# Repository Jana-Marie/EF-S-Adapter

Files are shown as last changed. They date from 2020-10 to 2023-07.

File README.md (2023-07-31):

# EF-S-Adapter

Hard- and Firmware to control EF/EF-S lenses. The protocol used has grown since the first generation of EF(-S) lenses hence is a bit extensive with different layers of compatibility. On the physical layer a SPI like interface is used with I2S alike clock-stretching. 

**Please use at your own risk, the hard- and firmware are experimental and can damage your lens!**

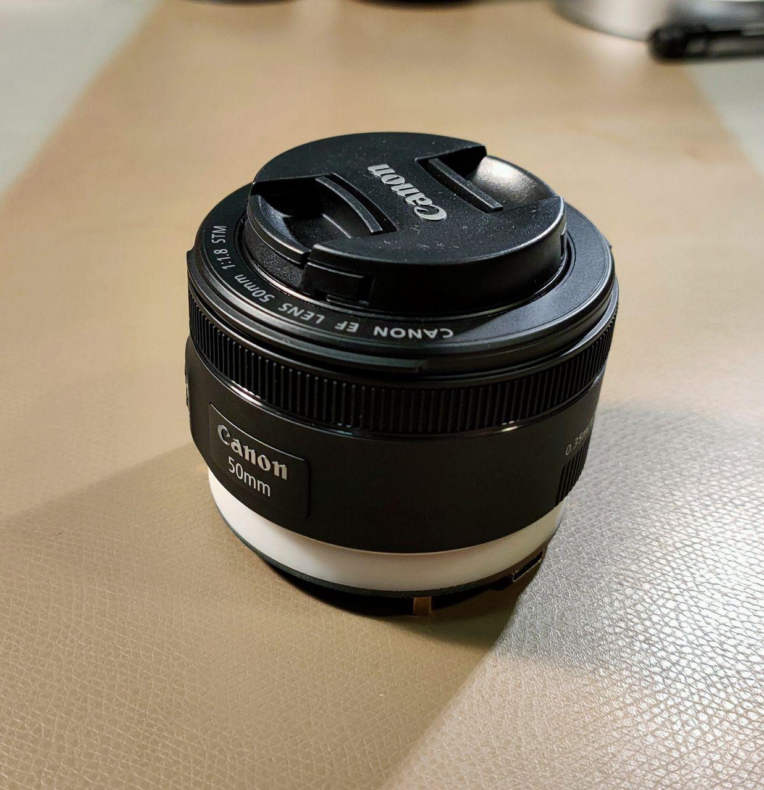
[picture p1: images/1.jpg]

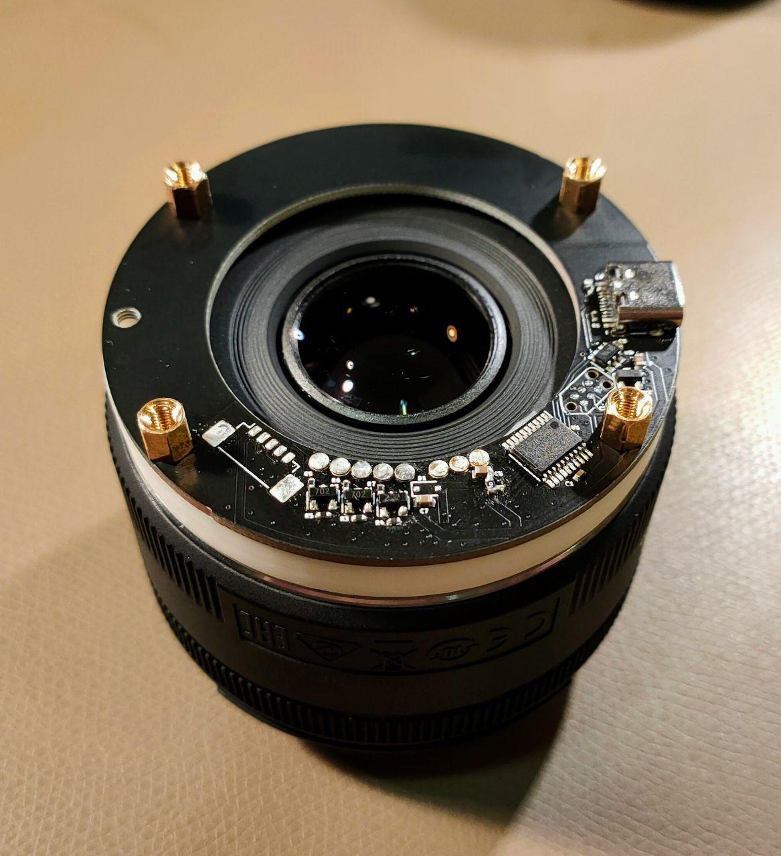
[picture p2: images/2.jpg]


### Status

##### v1
 
  - Tested
  - May shorts power rails on lens attachment
  
##### v1.1

 - Tested

### Todo

 - [x] Make lens hotplugable (needs new hardware revision)
 - [ ] Create helper functions (like set_aperture_to(aperture))
 - [ ] Documentation

### Thanks

Thanks to [Jean](https://pickandplace.wordpress.com/2011/10/05/canon-ef-s-protocol-and-electronic-follow-focus/) for this blogpost!

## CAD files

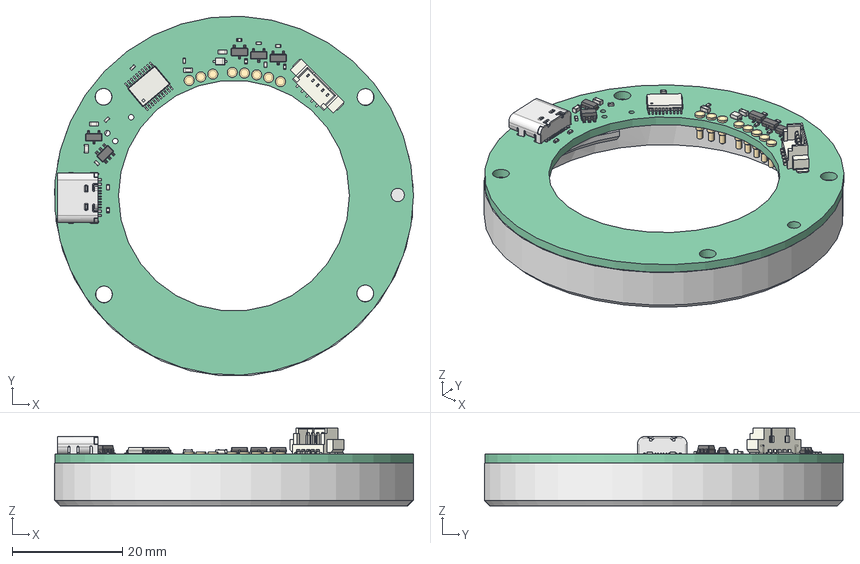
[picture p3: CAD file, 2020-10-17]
CAD/lensmount_3d.FCStd
65.0 x 65.1 x 14.1 mm
Pcb_cc020
J5_mill-max-0964-0-15-20-85-14-11-0_5F3EEFC005
J6_mill-max-0964-0-15-20-85-14-11-0_5F3EEFBF001
J4_mill-max-0964-0-15-20-85-14-11-0_5F3EEFBA001
J7_mill-max-0964-0-15-20-85-14-11-0_5F3EEFB006
J3_mill-max-0964-0-15-20-85-14-11-0_5F3EEFB001
J8_mill-max-0964-0-15-20-85-14-11-0_5F3EEFAB001
J2_mill-max-0964-0-15-20-85-14-11-0_5F3EEFA007
J1_mill-max-0964-0-15-20-85-14-11-0_5F3EEFA002
U3_SOT_23_6_5F3F1C038
U2_SOT_23_5F3F006B001
R9_R_0402_1005Metric_5F3F0011
R8_R_0402_1005Metric_5F3F0010
R7_R_0402_1005Metric_5F3F0E057
R6_R_0402_1005Metric_5F3EFFFB001
R5_R_0402_1005Metric_5F3EFFF005
R4_R_0402_1005Metric_5F3EFFED001
R3_R_0402_1005Metric_5F3EFFE007
R2_R_0402_1005Metric_5F3EFFDF001
R1_R_0402_1005Metric_5F3EFFD009
Q3_SOT_23_5F3EFFD002
Q2_SOT_23_5F3F0DD004
Q1_SOT_23_5F3EFFA008
J10_Molex_53398_0571_5F3EFF7D001
D1_D_SOD_323F_5F3EFEE002
C7_C_0603_1608Metric_5F3EFEC010
C6_C_0603_1608Metric_5F3EFEC003
C5_C_0402_1005Metric_5F3EFEBB001
C4_C_0603_1608Metric_5F3EFEB005
C3_C_0603_1608Metric_5F3EFEAD001
C2_C_0402_1005Metric_5F3EFEA007
C1_C_0402_1005Metric_5F3EFE9F001
J9_HRO_TYPE-C-31-M-12(1)_5F3EFB50
U1_TSSOP_20_44x65mm_P065mm_5F3EF99D001

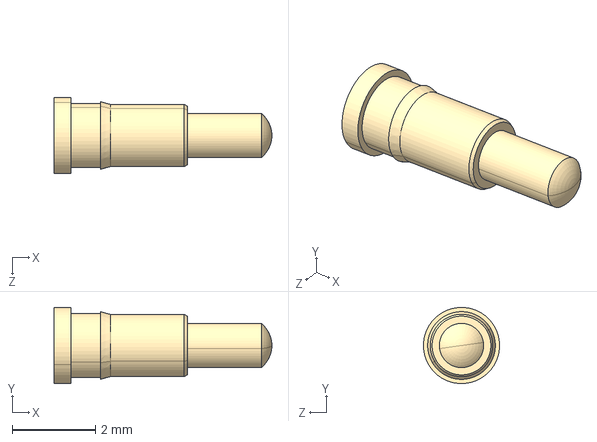
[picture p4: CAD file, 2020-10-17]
hardware/v1.1/mill-max-0964-0-15-20-85-14-11-0.step
5.23 x 1.83 x 1.83 mm

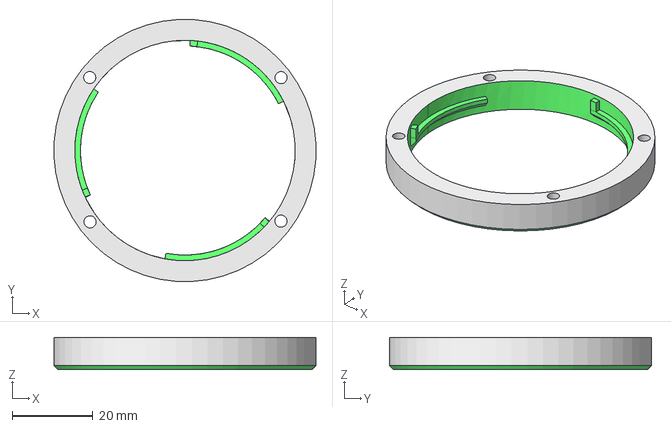
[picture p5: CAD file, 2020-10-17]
CAD/lensmount.step
64.9 x 64.9 x 7.95 mm

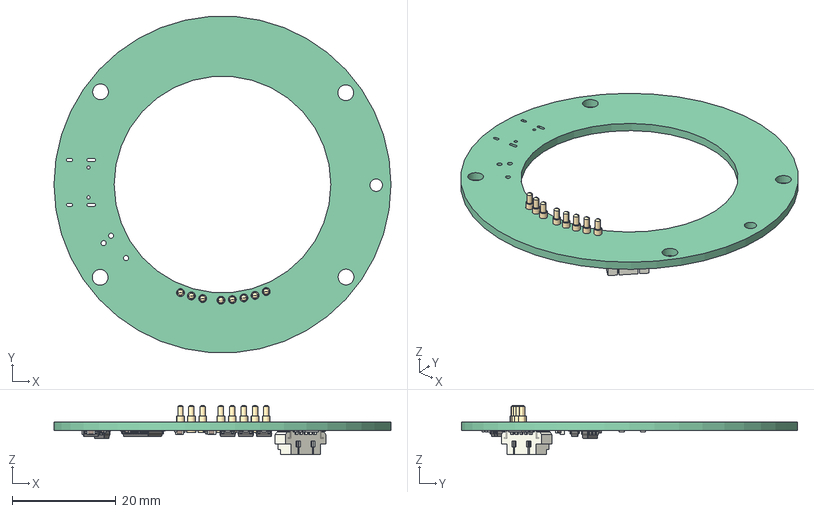
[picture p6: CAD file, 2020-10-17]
CAD/lensmount_pcb.step
65.0 x 64.8 x 9.53 mm
Local_CS_cc19
Pcb_cc19
PCB_Sketch_cc19
J5_mill-max-0964-0-15-20-85-14-11-0_5F3EEFC4
J6_mill-max-0964-0-15-20-85-14-11-0_5F3EEFBF
J4_mill-max-0964-0-15-20-85-14-11-0_5F3EEFBA
J7_mill-max-0964-0-15-20-85-14-11-0_5F3EEFB5
J3_mill-max-0964-0-15-20-85-14-11-0_5F3EEFB0
J8_mill-max-0964-0-15-20-85-14-11-0_5F3EEFAB
J2_mill-max-0964-0-15-20-85-14-11-0_5F3EEFA6
J1_mill-max-0964-0-15-20-85-14-11-0_5F3EEFA1
U3_SOT_23_6_5F3F1C37
U2_SOT_23_5F3F006B
R9_R_0402_1005Metric_5F3F0010
R8_R_0402_1005Metric_5F3F0009
R7_R_0402_1005Metric_5F3F0E56
R6_R_0402_1005Metric_5F3EFFFB
R5_R_0402_1005Metric_5F3EFFF4
R4_R_0402_1005Metric_5F3EFFED
R3_R_0402_1005Metric_5F3EFFE6
R2_R_0402_1005Metric_5F3EFFDF
R1_R_0402_1005Metric_5F3EFFD8
Q3_SOT_23_5F3EFFD1
Q2_SOT_23_5F3F0DD3
Q1_SOT_23_5F3EFFA7
J10_Molex_53398_0571_5F3EFF7D
D1_D_SOD_323F_5F3EFEE1
C7_C_0603_1608Metric_5F3EFEC9
C6_C_0603_1608Metric_5F3EFEC2
C5_C_0402_1005Metric_5F3EFEBB
C4_C_0603_1608Metric_5F3EFEB4
C3_C_0603_1608Metric_5F3EFEAD
C2_C_0402_1005Metric_5F3EFEA6
C1_C_0402_1005Metric_5F3EFE9F
U1_TSSOP_20_44x65mm_P065mm_5F3EF99D

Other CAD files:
hardware/v1/lensmount.obj

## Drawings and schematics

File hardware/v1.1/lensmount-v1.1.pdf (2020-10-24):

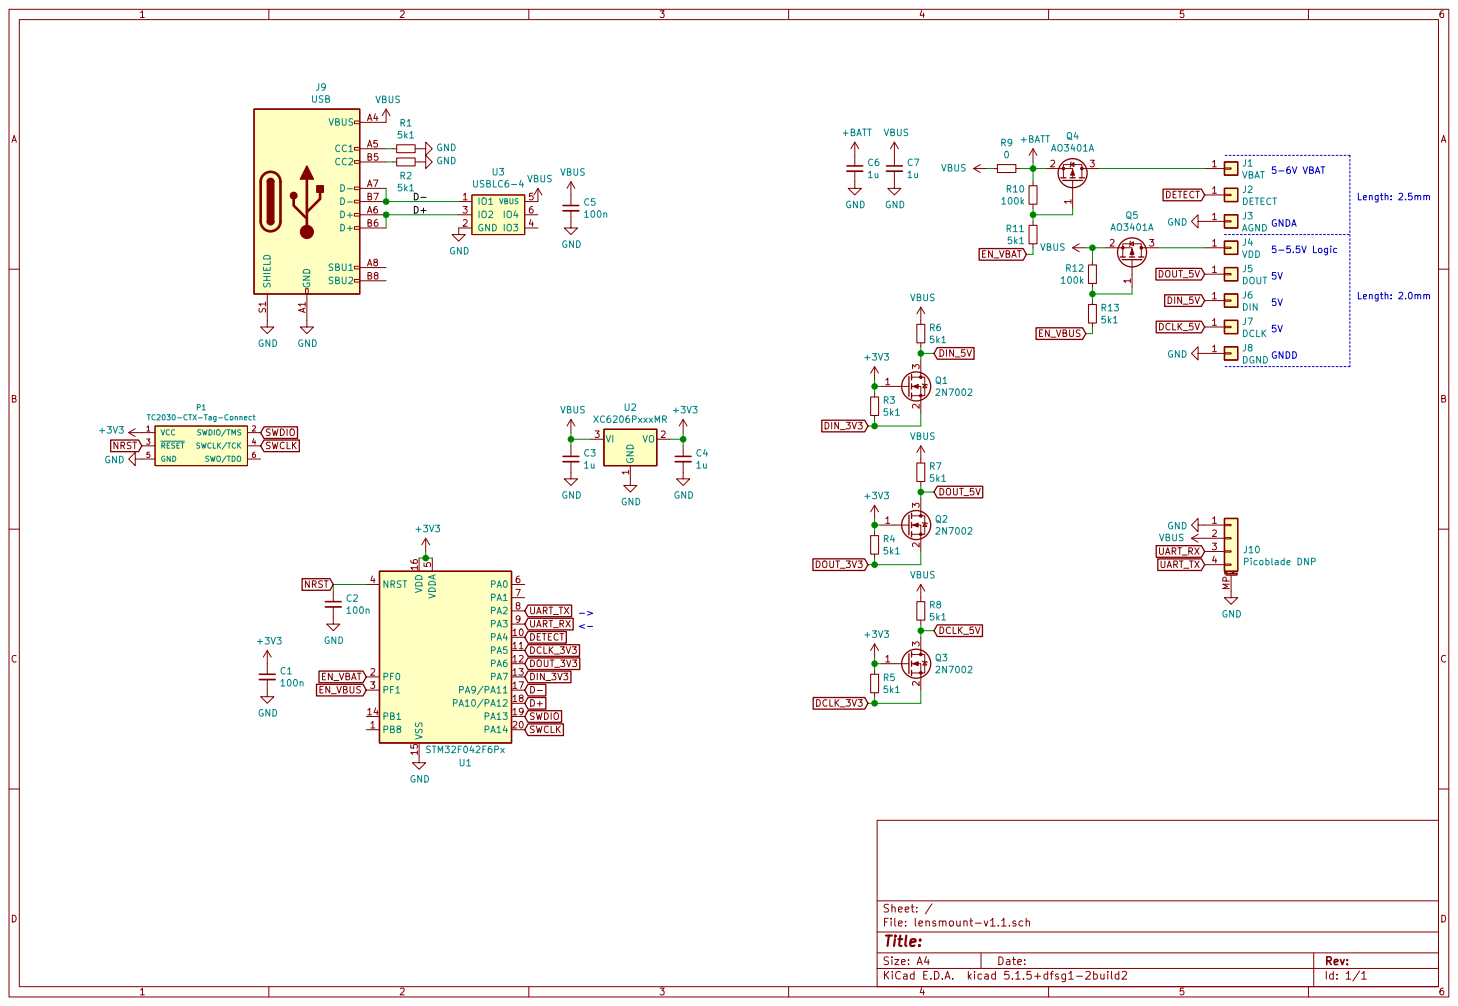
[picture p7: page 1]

Id: 1/1 Title: File: lensmount-v1.1.sch Sheet: /

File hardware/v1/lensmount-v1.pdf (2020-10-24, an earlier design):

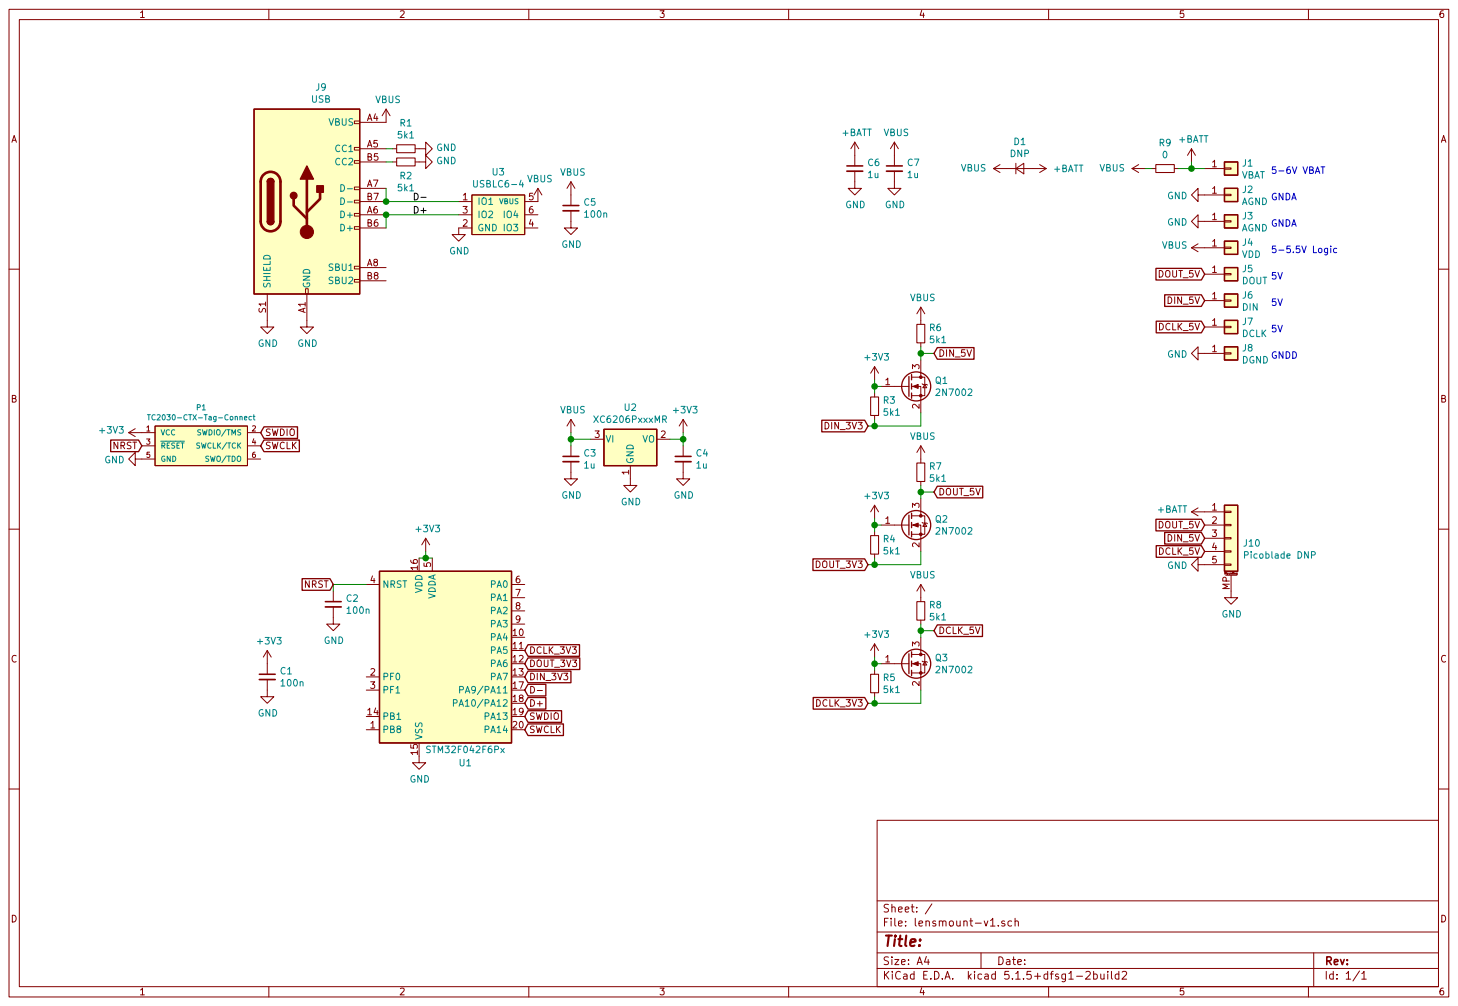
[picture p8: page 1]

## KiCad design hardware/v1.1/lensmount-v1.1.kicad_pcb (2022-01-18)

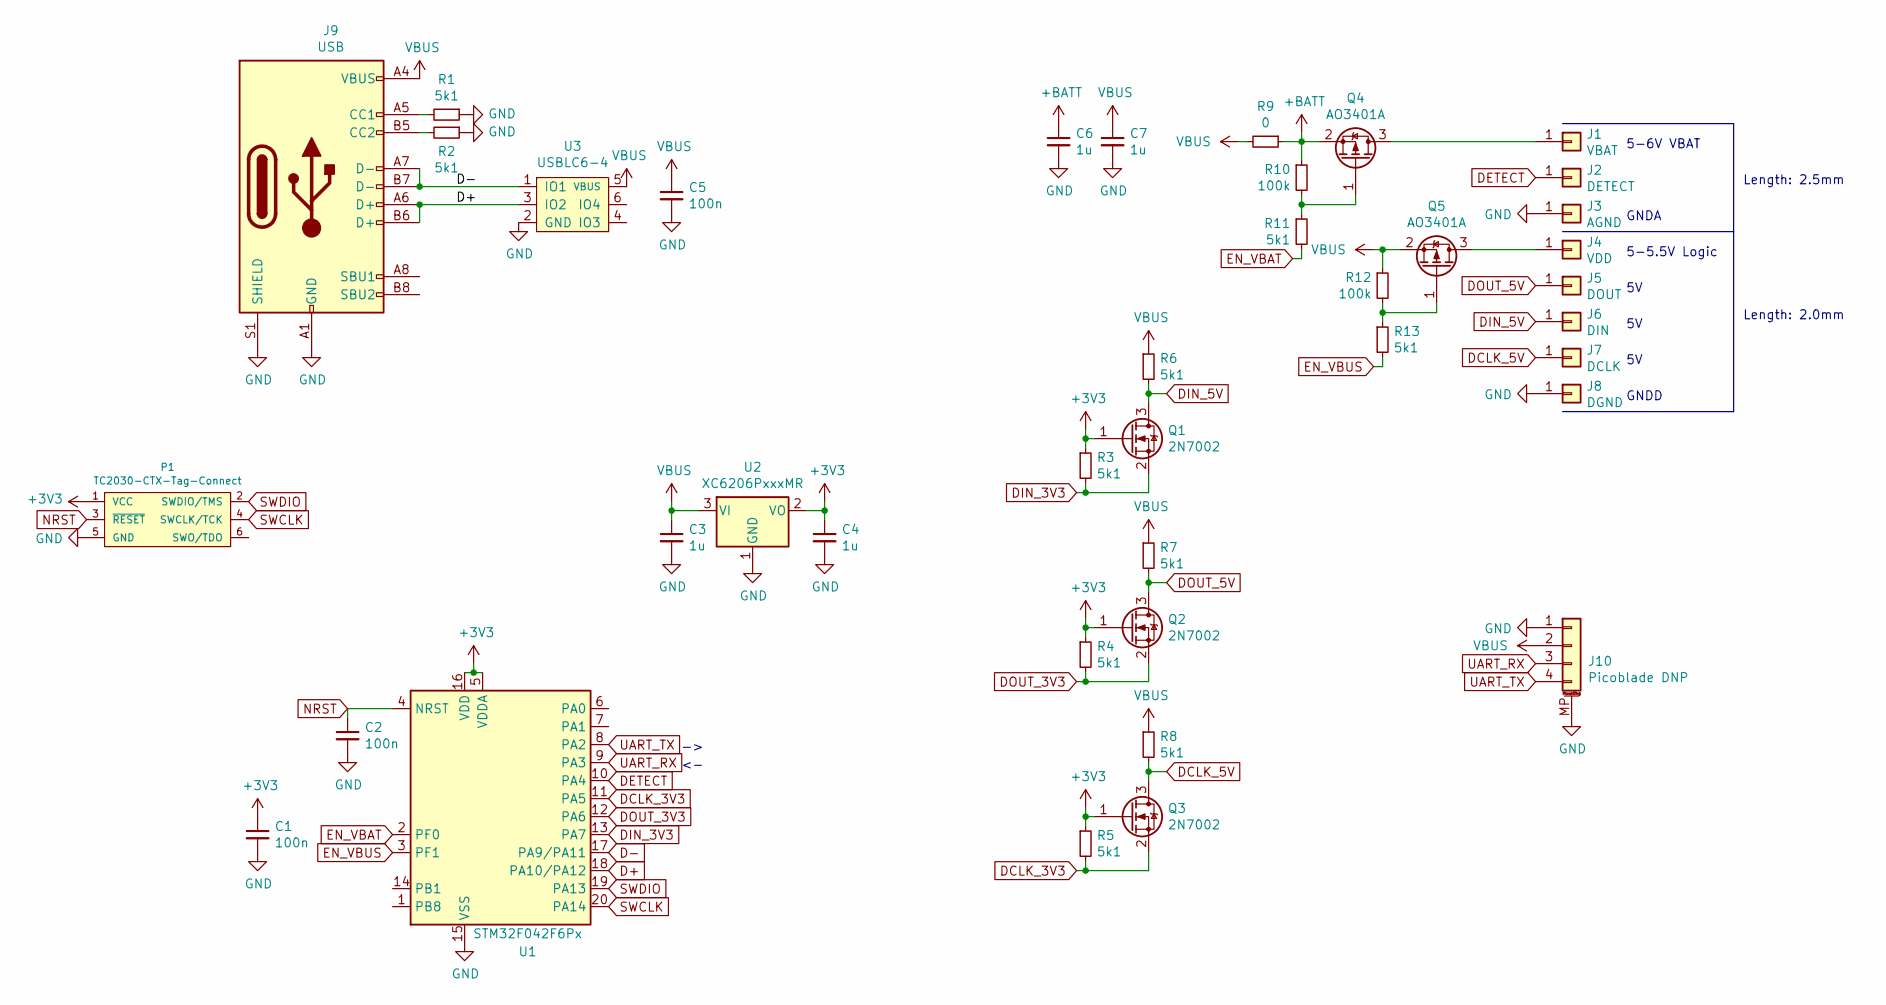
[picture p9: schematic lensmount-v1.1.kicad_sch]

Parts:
C1, C2, C5: 100n; C_0402
C3, C4, C6, C7: 1u; C_0603
J1: VBAT; PH-MVF-5365; Mouser 581-709150001025006
J2: DETECT; PH-MVF-5365; Mouser 581-709150001025006
J3: AGND; PH-MVF-5365; Mouser 581-709150001025006
J4: VDD; PH-MVF-5365; Mouser 581-709150001020006
J5: DOUT; PH-MVF-5365; Mouser 581-709150001020006
J6: DIN; PH-MVF-5365; Mouser 581-709150001020006
J7: DCLK; PH-MVF-5365; Mouser 581-709150001020006
J8: DGND; PH-MVF-5365; Mouser 581-709150001020006
J9: USB; USB-C 16Pin
J10: Picoblade DNP; Molex_PicoBlade_53398-0471_1x04-1MP_P1.25mm_Vertical
P1: TC2030-CTX-Tag-Connect; TC2030
Q1, Q2, Q3: 2N7002; SOT-23
Q4, Q5: AO3401A; SOT-23
R1, R2, R3, R4, R5, R6, R7, R8, R11, R13: 5k1; R_0402
R9: 0; R_0402
R10, R12: 100k; R_0402
U1: STM32F042F6Px; TSSOP-20_4.4x6.5mm_P0.65mm
U2: XC6206PxxxMR; SOT-23
U3: USBLC6-4; SOT-23-6

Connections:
+3V3: C1.1, C4.1, P1.1 (VCC), Q1.1 (G), Q2.1 (G), Q3.1 (G), R3.1, R4.1, R5.1, U1.5 (VDDA), U1.16 (VDD), U2.2 (VO)
+BATT: C6.1, Q4.2 (S), R9.1, R10.1
D+: J9.A6 (D+), J9.B6 (D+), U1.18 (PA10/PA12), U3.3 (IO2)
D-: J9.A7 (D-), J9.B7 (D-), U1.17 (PA9/PA11), U3.1 (IO1)
DCLK_3V3: Q3.2 (S), R5.2, U1.11 (PA5)
DCLK_5V: J7.1, Q3.3 (D), R8.2
DETECT: J2.1, U1.10 (PA4)
DIN_3V3: Q1.2 (S), R3.2, U1.13 (PA7)
DIN_5V: J6.1, Q1.3 (D), R6.2
DOUT_3V3: Q2.2 (S), R4.2, U1.12 (PA6)
DOUT_5V: J5.1, Q2.3 (D), R7.2
EN_VBAT: R11.2, U1.2 (PF0)
EN_VBUS: R13.2, U1.3 (PF1)
GND: C1.2, C2.2, C3.2, C4.2, C5.2, C6.2, C7.2, J3.1, J8.1, J9.A1 (GND), J9.A12 (GND), J9.B1 (GND), J9.B12 (GND), J9.S1 (SHIELD), J10.1, J10.MP (MountPin), P1.5 (GND), R1.1, R2.1, U1.15 (VSS), U2.1 (GND), U3.2 (GND)
NRST: C2.1, P1.3 (~RESET), U1.4 (NRST)
unnamed: J1.1, Q4.3 (D)
unnamed: J4.1, Q5.3 (D)
unnamed: J9.A5 (CC1), R1.2
unnamed: J9.B5 (CC2), R2.2
unnamed: Q4.1 (G), R10.2, R11.1
unnamed: Q5.1 (G), R12.2, R13.1
SWCLK: P1.4 (SWCLK/TCK), U1.20 (PA14)
SWDIO: P1.2 (SWDIO/TMS), U1.19 (PA13)
UART_RX: J10.3, U1.9 (PA3)
UART_TX: J10.4, U1.8 (PA2)
VBUS: C3.1, C5.1, C7.1, J9.A4 (VBUS), J9.A9 (VBUS), J9.B4 (VBUS), J9.B9 (VBUS), J10.2, Q5.2 (S), R6.1, R7.1, R8.1, R9.2, R12.1, U2.3 (VI), U3.5 (VBUS)

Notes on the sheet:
5-6V VBAT
Length: 2.5mm
GNDD
Length: 2.0mm
5-5.5V Logic
GNDA

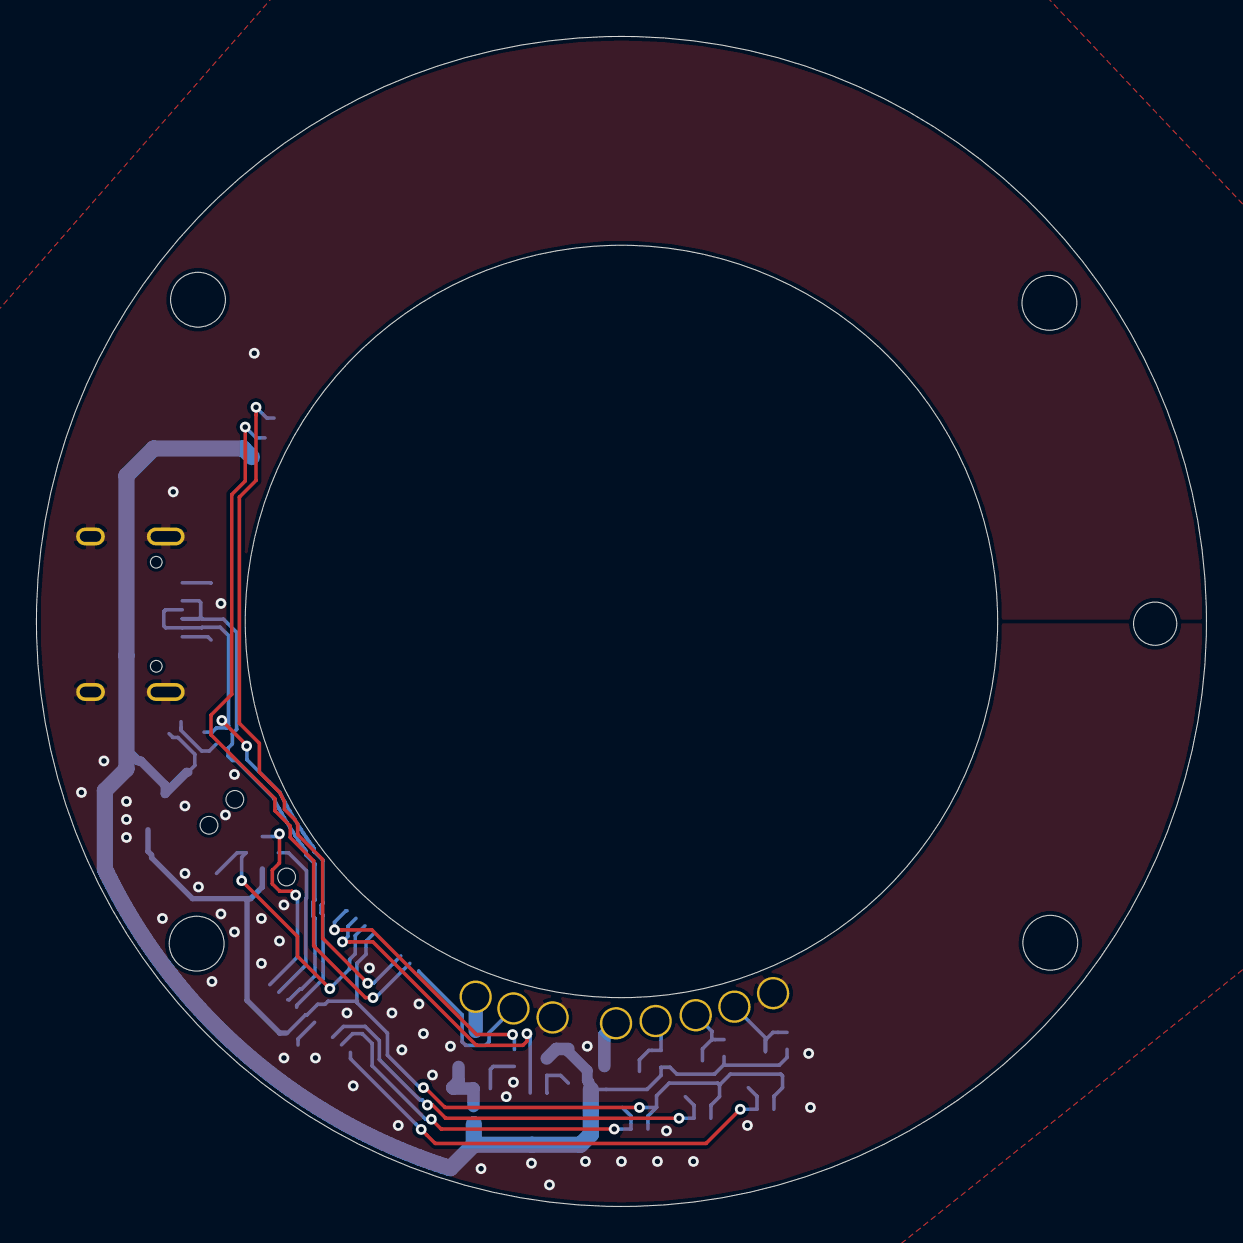
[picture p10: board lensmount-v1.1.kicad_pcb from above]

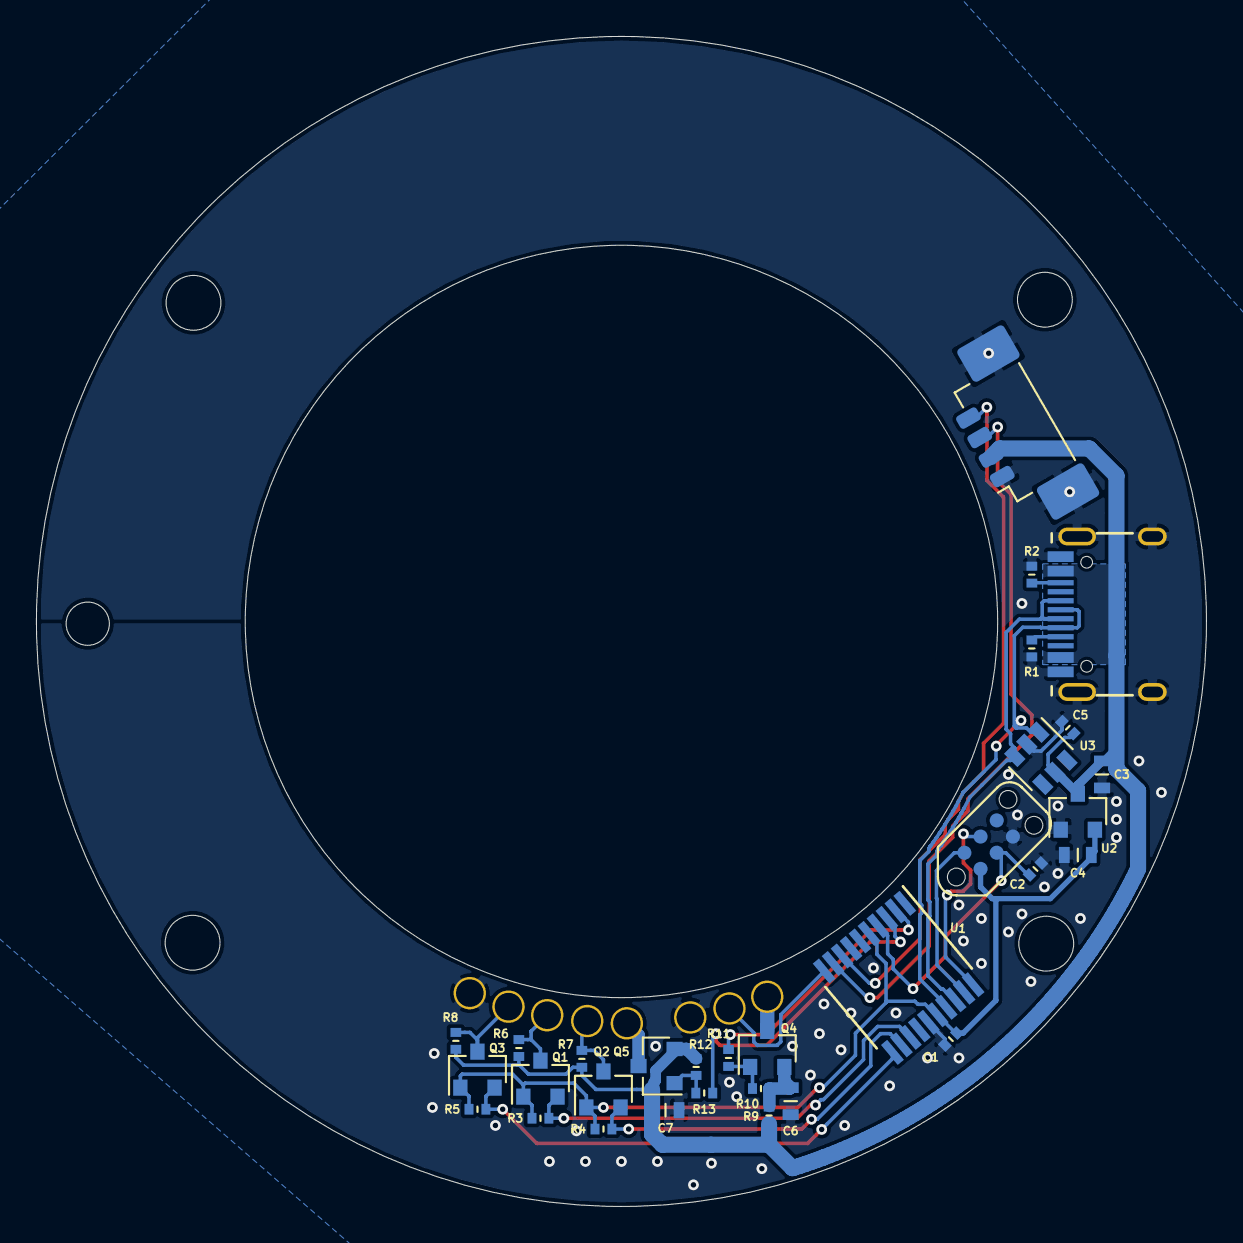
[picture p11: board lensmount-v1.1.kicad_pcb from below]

Board: 2 copper layers, 65.0 x 65.0 mm, 39 parts (31 on the bottom side), 26 nets.

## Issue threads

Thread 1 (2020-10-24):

Add license information

vazhnov, 2020-10-24:
Hello!

I found link to this project from https://hackaday.com/2020/10/24/proprietary-lenses-are-no-problem-with-this-usb-adaptor/

Could you please add information about license of this repository — is it allowed to copy, change and use code in any purpose?
It would be great to see any popular open source license.

Jan--Henrik, 2020-10-24:
Thank you for your input, I've added a license. :)

vazhnov, 2020-10-24:
MIT — great!
Thank you very much!

Closed 2020-10-24.

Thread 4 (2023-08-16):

Some lenses seem to not work

aslidegh, 2023-08-16:
Hey, great project, I hope it is still alive!
I was wondering, if you had ever tested this with EF 100 Macro, EF 24-70 2.8 II or 16-35 f4 lenses. While other lenses seem to work fine, I keep getting 0xFF when busy polling above mentioned lenses.
Any ideas?

Jana-Marie, 2023-08-21:
Hey, sorry for the late reply. Glad that you replicated and like the project :3

I'm still active, but I also haven't touched this project in a while. Is it correct that all the lenses that do not work are rather modern "red-ring" lenses? Are all working lenses "non-red-ring" lenses?

aslidegh, 2023-08-22:
Hey,
mmh yeah kind of. My tests are as follows:
- 50mm f1.8 STM ; works (I think this version of the lens is also kind of "new")
- 70-200 f4 red-ring ; works (but it's very old)
- 24-70 f2.8 II red-ring ; not working
- 100 f2.8 macro red-ring ; not working
- 16-35 f4 red-ring ; not working

Are you observing similar issue?

jeanthom, 2023-08-22:
I came across this: http://oliford.co.uk/phys/canon-lens-protocol/canon-135mm-switchOn-x3 (Canon 135mm L, old lens but red ring). It seems like the init sequence goes with more than just 0x0A on the body side for these lens. It legacy from the analog EF era?

This is sort of confirmed in http://jp79dsfr.free.fr/_Docs%20et%20infos/Photo%20Tech%20_%20Canon%20EOS-EF%20Protocol.pdf:

> Commande 0x0A : Demande disponibilité objectif
>
> Cette commande est généralement la première rencontrée lors de l'émission d'une trame. Elle
est alors répétée jusqu'à obtention d'une réponse 0xAA de la part de l'objectif, d'autres commandes
pouvant alors suivre. Cette méthode de fonctionnement est typique d'un test de réponse-
acquittement comme celui utilisé en communication série Ascii avec ENQ/ACK (ou TcpIp avec
Syn/Ack mais nettement moins d'actualité lors de la conception du protocole en 1987).
>
> On retrouve ce principe dans l'essai précédent sans objectif ou une suite massive de commande
0x0A était émise avant abandon ou tentative ultérieure. Avec l'Eos 5000, ces suites de commande
0x0A sont suivies des commandes 0X09, 0E, 0F ce qui peut laisser supposer que celles-ci
correspondent a des ordres d'initialisation ou de reset. Il est à noter que 0x0E ne sera rencontré
ultérieurement qu'avec des objectifs réglés en autofocus manuel.

...or in English:

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

aslidegh, 2023-08-24:
I did already modify the init procedure doing similar, but seems like it doesn't change anything for me at least.

Jana-Marie, 2023-08-24:
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

Thanks! I have not experienced similar issues, but I also do not own a red-ring lens. Thanks for the test!

Jana-Marie, 2023-08-24:
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

Thanks to you too! I will look into it next week, maybe I can find something

aslidegh, 2023-09-06:
I digged a bit more but couldn't find any useful information related to newer red ring lenses unfortunately.

whoigaurav, 2024-10-29:
can anyone add a bin file or hex file for the stm32 programmer?

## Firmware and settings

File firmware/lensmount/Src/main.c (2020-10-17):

#include "main.h"
#include "lens.h"

PCD_HandleTypeDef hpcd_USB_FS;

void SystemClock_Config(void);
static void MX_GPIO_Init(void);
static void MX_USB_PCD_Init(void);

extern struct lensinfo_t lens;
extern uint8_t r_buf[40];
int8_t _tmp;

int main(void)
{

  HAL_Init();
  SystemClock_Config();
  MX_GPIO_Init();
  MX_USB_PCD_Init();

  lens_init();

  /*
  clock 80khz
  commands:
  0x9701 or 0x97CA returns 7 bytes (ID,Min/Max Zoom,Version,Brand)
  0xB0 returns 4 bytes (Min/Max Aperture)
  0xA0 returns 2 bytes (Current Zoom Value)
  0x0713xx returns 1 byte (0x11) xx set Aperture to xx stops
  0x1380 returns 1 byte (0x11) reopen Aperture
  0x0A busy poll (returns 0xAA if busy)
  0xC0 returns 2 bytes USM motor position
  0x05 turn focus ring to min
  0x06 turn focus ring to max
  0x44xxxx turn focus ring xxxxsteps relative (1s complement)
  */

  HAL_Delay(100);
  lens_get_info();
  /*
  lens_open_aperture();
  lens_set_aperture(-50);
  HAL_Delay(100);
  lens_focus_min();
  HAL_Delay(100);
  */
  lens_open_aperture();

  while (1)
  {

    for(int i = 0; i <= 20; i++){
      lens_dec_aperture();
      HAL_Delay(100);
    }
    HAL_Delay(1500);

    lens_focus_max();
    HAL_Delay(1500);

    lens_open_aperture();
    HAL_Delay(1500);

    lens_focus_max();
    for(int i = 0; i <= 120; i++){
      lens_move_focus(-30);
      HAL_Delay(30);
    }
    lens_focus_min();
    HAL_Delay(1500);
  }
}

void SystemClock_Config(void)
{
  RCC_OscInitTypeDef RCC_OscInitStruct = {0};
  RCC_ClkInitTypeDef RCC_ClkInitStruct = {0};
  RCC_PeriphCLKInitTypeDef PeriphClkInit = {0};

  RCC_OscInitStruct.OscillatorType = RCC_OSCILLATORTYPE_HSI48;
  RCC_OscInitStruct.HSI48State = RCC_HSI48_ON;
  RCC_OscInitStruct.PLL.PLLState = RCC_PLL_NONE;
  HAL_RCC_OscConfig(&RCC_OscInitStruct);

  RCC_ClkInitStruct.ClockType = RCC_CLOCKTYPE_HCLK|RCC_CLOCKTYPE_SYSCLK
                              |RCC_CLOCKTYPE_PCLK1;
  RCC_ClkInitStruct.SYSCLKSource = RCC_SYSCLKSOURCE_HSI48;
  RCC_ClkInitStruct.AHBCLKDivider = RCC_SYSCLK_DIV1;
  RCC_ClkInitStruct.APB1CLKDivider = RCC_HCLK_DIV4;

  HAL_RCC_ClockConfig(&RCC_ClkInitStruct, FLASH_LATENCY_1);

  PeriphClkInit.PeriphClockSelection = RCC_PERIPHCLK_USB;
  PeriphClkInit.UsbClockSelection = RCC_USBCLKSOURCE_HSI48;

  HAL_RCCEx_PeriphCLKConfig(&PeriphClkInit);
}


static void MX_USB_PCD_Init(void)
{
  hpcd_USB_FS.Instance = USB;
  hpcd_USB_FS.Init.dev_endpoints = 8;
  hpcd_USB_FS.Init.speed = PCD_SPEED_FULL;
  hpcd_USB_FS.Init.phy_itface = PCD_PHY_EMBEDDED;
  hpcd_USB_FS.Init.low_power_enable = DISABLE;
  hpcd_USB_FS.Init.lpm_enable = DISABLE;
  hpcd_USB_FS.Init.battery_charging_enable = DISABLE;
  HAL_PCD_Init(&hpcd_USB_FS);
}

static void MX_GPIO_Init(void)
{
  __HAL_RCC_GPIOA_CLK_ENABLE();

  GPIO_InitTypeDef GPIO_InitStruct = {0};

  GPIO_InitStruct.Pin = GPIO_PIN_5;
  GPIO_InitStruct.Mode = GPIO_MODE_OUTPUT_OD;
  GPIO_InitStruct.Pull = GPIO_PULLUP;
  GPIO_InitStruct.Speed = GPIO_SPEED_FREQ_HIGH;
  HAL_GPIO_Init(GPIOA, &GPIO_InitStruct);

  GPIO_InitStruct.Pin = GPIO_PIN_7;
  GPIO_InitStruct.Mode = GPIO_MODE_OUTPUT_OD;
  GPIO_InitStruct.Pull = GPIO_PULLUP;
  GPIO_InitStruct.Speed = GPIO_SPEED_FREQ_HIGH;
  HAL_GPIO_Init(GPIOA, &GPIO_InitStruct);

  GPIO_InitStruct.Pin = GPIO_PIN_6;
  GPIO_InitStruct.Mode = GPIO_MODE_OUTPUT_OD;
  GPIO_InitStruct.Pull = GPIO_PULLUP;
  GPIO_InitStruct.Speed = GPIO_SPEED_FREQ_HIGH;
  HAL_GPIO_Init(GPIOA, &GPIO_InitStruct);

}

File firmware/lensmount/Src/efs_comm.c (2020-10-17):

#include "efs_comm.h"

void efs_delay(uint32_t delay) {
  while(delay--){
    asm("NOP");
  }
}

void efs_wait() {
  efs_delay(60);
  while(HAL_GPIO_ReadPin(GPIOA, GPIO_PIN_5) == 0){ // Wait until lens is not busy anymore
    asm("NOP");
  }
}

uint8_t reverse(uint8_t data) {
   data = (data & 0xF0) >> 4 | (data & 0x0F) << 4;
   data = (data & 0xCC) >> 2 | (data & 0x33) << 2;
   data = (data & 0xAA) >> 1 | (data & 0x55) << 1;
   return data;
}

void efs_send(uint8_t data) {
  HAL_GPIO_WritePin(GPIOA, GPIO_PIN_7, 0);
  efs_sr(data);
  HAL_GPIO_WritePin(GPIOA, GPIO_PIN_7, 1);
  efs_wait();
  efs_delay(100);
}

uint8_t efs_receive() {
  uint8_t rec = efs_sr(0x00);
  efs_wait();
  efs_delay(100);
  return rec;
}


uint8_t efs_sr(uint8_t data) {
  data = reverse(data);
  uint8_t rec = 0;
  uint8_t i;
  for(i = 0; i < 16; i++){
    HAL_GPIO_WritePin(GPIOA, GPIO_PIN_5, i & 1);
    if(i % 2 == 0){
      HAL_GPIO_WritePin(GPIOA, GPIO_PIN_6, (data >> (i/ 2)) & 1);
    } else {
      rec |= (HAL_GPIO_ReadPin(GPIOA, GPIO_PIN_7) << (((16-i))/ 2));
    }
    efs_delay(33);
  }
  HAL_GPIO_WritePin(GPIOA, GPIO_PIN_6, 0);
  return rec;
}

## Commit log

2020-10-17 added hardware
    [lensmount-v1-B_Cu.gbl, lensmount-v1-B_Mask.gbs, lensmount-v1-B_Paste.gbp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]
2020-10-17 added CAD
    [lensmount.step, lensmount_3d.FCStd, lensmount_pcb.step]
2020-10-17 added hardware v1.1
    [lensmount-v1-B_Cu.gbl, lensmount-v1-B_Mask.gbs, lensmount-v1-B_Paste.gbp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]
2020-10-18 updated v1.1
    [lensmount-v1.1-B_Cu.gbl, lensmount-v1.1-B_Mask.gbs, lensmount-v1.1-B_Paste.gbp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]
2022-01-18 updated to kicad6
    [lensmount-v1.1.kicad_pcb, lensmount-v1.1.kicad_sch, lensmount-v1.1.sch]
